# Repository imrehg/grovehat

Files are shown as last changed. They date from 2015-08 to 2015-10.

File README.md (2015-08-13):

# GroveHat for VIA VAB-820

[Grove][grove] break-out board for [VIA VAB-820](vab820).

Connectors:

 * 2 x I2C
 * 2 x Digital

[grove]: http://www.seeedstudio.com/wiki/Grove_System "Grove System"
[vab820]: http://www.viaembedded.com/en/boards/pico-itx/vab-820/ "VAB-820 product page"

## License

CERN Open Hardware License 1.2, see `LICENSE.txt`.

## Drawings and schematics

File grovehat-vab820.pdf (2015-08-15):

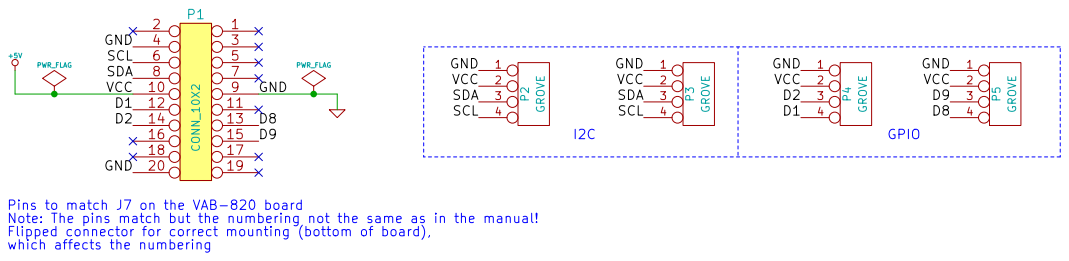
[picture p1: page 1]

Flipped connector for correct mounting (bottom of board),
which affects the numbering

CERN Open Hardware License 1.2
Moonpunch
File: grovehat-vab820.sch
Sheet: /
Title: GroveHat for VIA VAB-820
KiCad E.D.A.

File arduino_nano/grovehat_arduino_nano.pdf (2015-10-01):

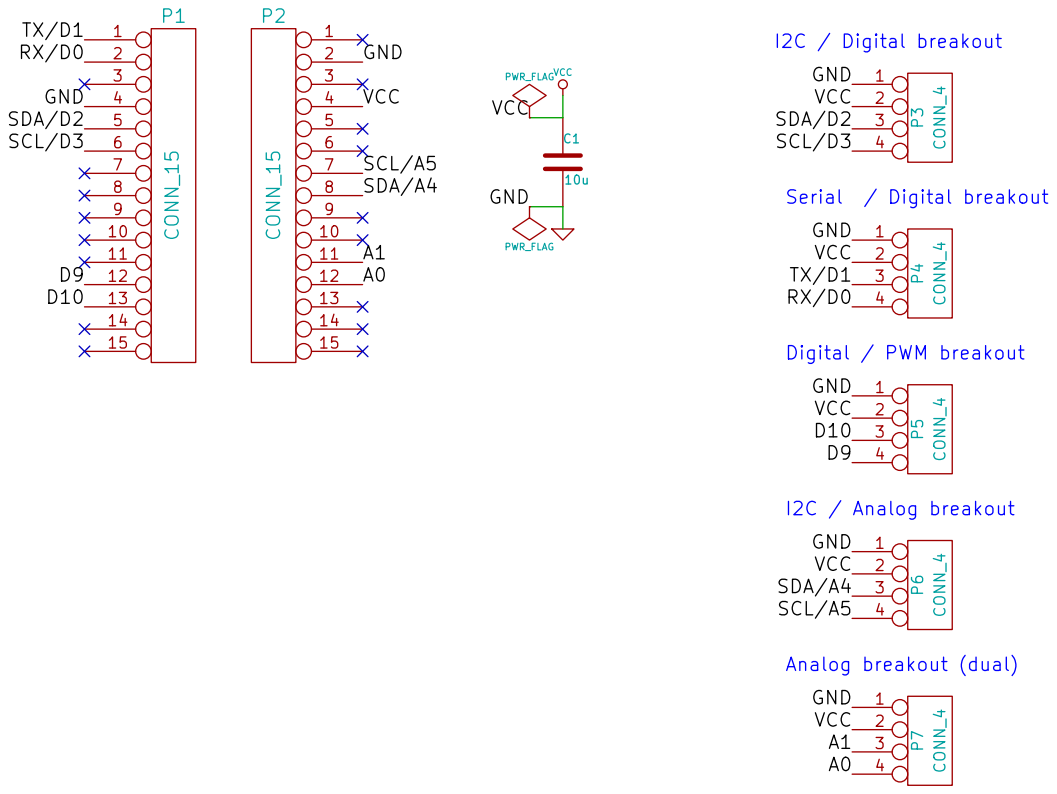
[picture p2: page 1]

Moonpunch
File: grovehat_arduino_nano.sch
Sheet: /
Title: GroveHat for Arduino Nano / Micro
KiCad E.D.A.

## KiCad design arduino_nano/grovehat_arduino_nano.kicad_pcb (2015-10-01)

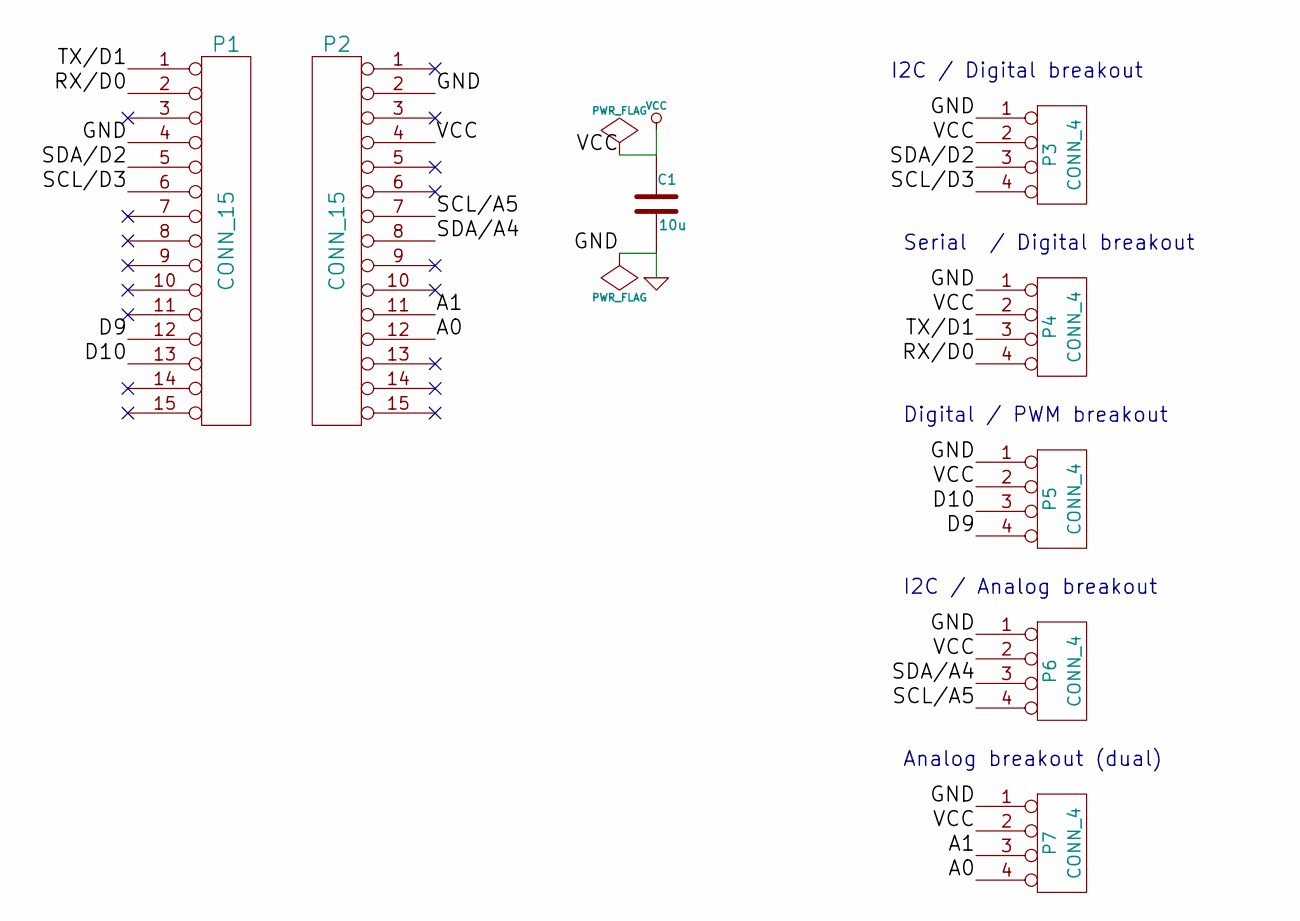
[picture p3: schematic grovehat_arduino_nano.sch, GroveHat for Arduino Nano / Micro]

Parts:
C1: 10u; SM0805
P1, P2: CONN_15
P3, P4, P6, P7: CONN_4; TWIG_2.0
P5: CONN_4

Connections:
/A0: P2.12, P7.4
/A1: P2.11, P7.3
/D9: P1.12, P5.4
/D10: P1.13, P5.3
/RX/D0: P1.2, P4.4
/SCL/A5: P2.7, P6.4
/SCL/D3: P1.6, P3.4
/SDA/A4: P2.8, P6.3
/SDA/D2: P1.5, P3.3
/TX/D1: P1.1, P4.3
GND: C1.2, P1.4, P2.2, P3.1, P4.1, P5.1, P6.1, P7.1
VCC: C1.1, P2.4, P3.2, P4.2, P5.2, P6.2, P7.2

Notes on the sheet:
I2C / Digital breakout
Serial / Digital breakout
Analog breakout (dual)
Digital / PWM breakout
I2C / Analog breakout

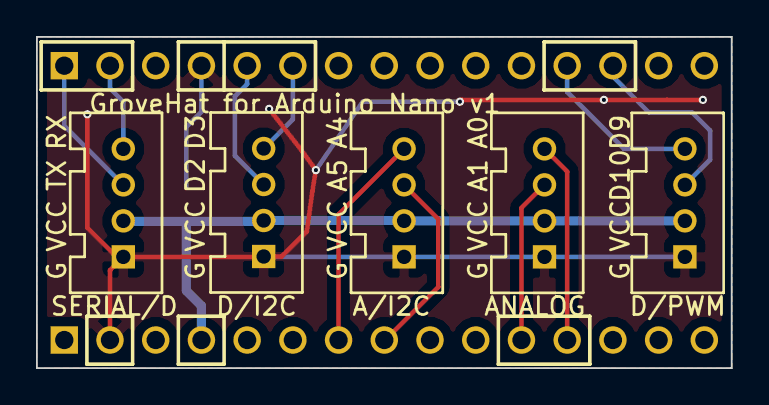
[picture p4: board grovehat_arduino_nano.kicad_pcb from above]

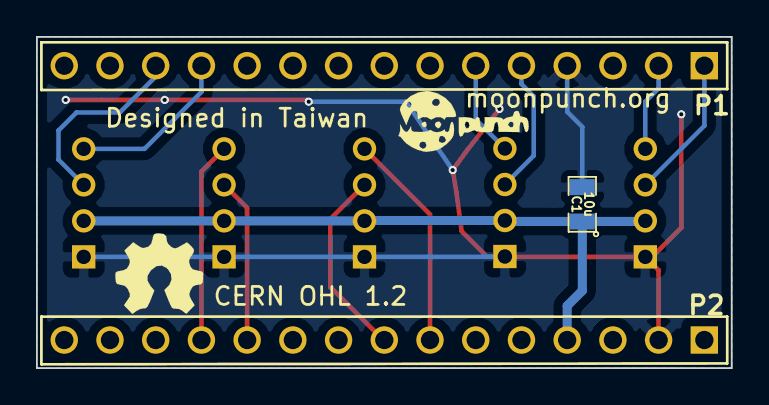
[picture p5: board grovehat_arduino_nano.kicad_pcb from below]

Board: 2 copper layers, 38.6 x 18.4 mm, 8 parts (3 on the bottom side), 12 nets.

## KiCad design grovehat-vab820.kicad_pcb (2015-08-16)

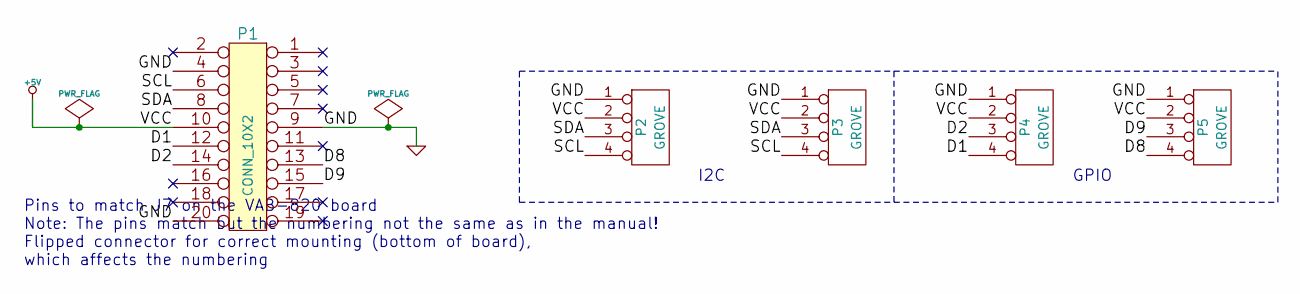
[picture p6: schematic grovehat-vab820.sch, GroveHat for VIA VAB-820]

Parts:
P1: CONN_10X2; pin_array_2mm_10x2
P2, P3, P4, P5: GROVE; TWIG_2.0

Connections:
+5V: P1.10, P2.2, P3.2, P4.2, P5.2
/D1: P1.12, P4.4
/D2: P1.14, P4.3
/D8: P1.13, P5.4
/D9: P1.15, P5.3
/SCL: P1.6, P2.4, P3.4
/SDA: P1.8, P2.3, P3.3
GND: P1.4, P1.9, P1.20, P2.1, P3.1, P4.1, P5.1

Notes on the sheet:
I2C
GPIO
Pins to match J7 on the VAB-820 board Note: The pins match but the numbering not the same as in the manual! Flipped connector for correct mounting (bottom of board), which affects the numbering

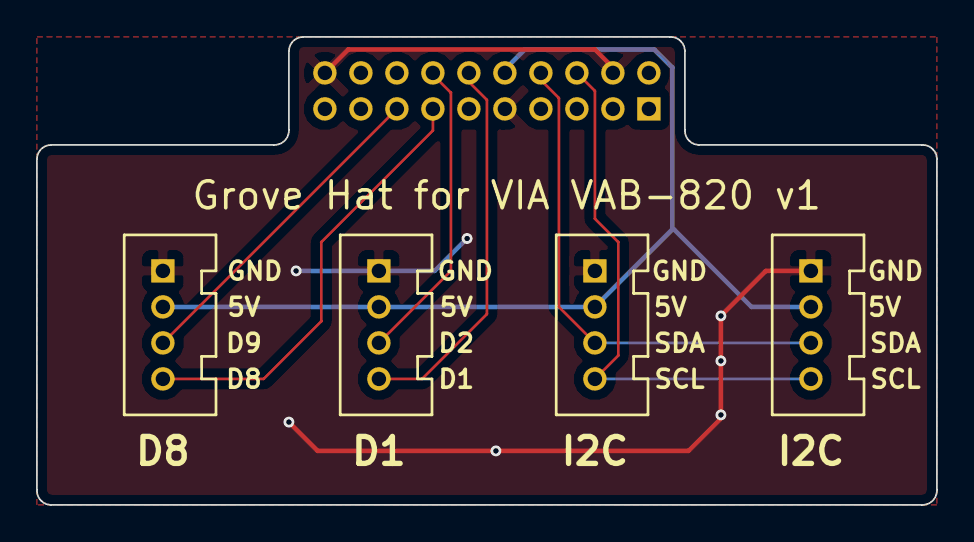
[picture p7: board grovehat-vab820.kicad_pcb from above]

Board: 2 copper layers, 50.0 x 26.0 mm, 5 parts (1 on the bottom side), 8 nets.

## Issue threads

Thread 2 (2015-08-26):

Flip signal lines between front and back

imrehg, 2015-08-26:
Put VCC on the front, and signal lines onto the back. Would make it possible to put the decoupling capacitor of #1 on the front. Also would leave better surface for the silkscreen labels.

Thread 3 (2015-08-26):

Board outline changes

imrehg, 2015-08-26:
1. Pull the neck of the board out further, so the actual breakout is not over the VAB-820 base board. This would allow not getting in the way of the corner screw.
2. Change the board into asymmetric, to be flush with the edge of the board on the side

For this I'll need to get the schematic of the VAB-820 board with the size markings. Where to get that?

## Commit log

2015-08-13 Schematic done
    [grovehat-vab820.sch]
2015-08-15 first draft of GrooveHat
    [grovehat-vab820-B_Cu.gbl, grovehat-vab820-B_Mask.gbs, grovehat-vab820-B_SilkS.gbo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]
2015-08-15 adjust silkscreen
    [grovehat-vab820.kicad_pcb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]
2015-08-16 updated PCB design, larger area, more spacious
    [grovehat-vab820-B_Cu.gbl, grovehat-vab820-B_Mask.gbs, grovehat-vab820-B_SilkS.gbo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]
2015-10-01 GroveHat for Arduino Nano v1
    As submitted for manufacturing.
    [grovehat_arduino_nano.kicad_pcb, grovehat_arduino_nano.sch]
2015-10-01 GroveHat for Arduino Nano v1 Gerber files
    [grovehat_arduino_nano-B_Cu.gbl, grovehat_arduino_nano-B_Mask.gbs, grovehat_arduino_nano-B_SilkS.gbo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]
2015-10-01 nano: add part numbers to the schematics
    [grovehat_arduino_nano.sch]

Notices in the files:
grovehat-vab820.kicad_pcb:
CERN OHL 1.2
